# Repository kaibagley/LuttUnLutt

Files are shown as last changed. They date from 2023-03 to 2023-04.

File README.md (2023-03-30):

### 

3x5+2 key split orthogonal BLE keyboard

This fork is a custom version of weteor's Lütt un Lütt, altered such that it is powered by a pair of LiPO batteries rather than coin cells, and uses MX switches.

## Features

- Diode-less pcb, since there are enough GPIO pins on the nice!nano
- full BLE, powered by 3.7v 110mAh LiPO batteries
- MX hotswap sockets
- case files are supplied (stl, dxf, as well as the freecad files)
- supports both nice!nano and pro micro
- QMK, ZMK, etc. support with pro micro, or ZMK with nice!nano

## Prototype

- First prototype printed on 18th March 2023

## what's left to do?

- fix small hole placement error in case
- implement support of Elite-C/Pi
- add mounting holes

## Credit

This repo is inspired by weteor's Lütt un Lütt, please visit this link: https://github.com/weteor/LuttUnLutt to view the original, and support the creator.

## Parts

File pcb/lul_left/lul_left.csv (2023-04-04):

Source: | G:\Keyboards\Thunder-Lightning\pcb\lul_left\lul_left.kicad_sch
Date: | 18/03/2023 10:16:14 PM
Tool: | Eeschema (7.0.0)
Generator: | C:\Program Files\KiCad\7.0\bin\scripting\plugins/bom_csv_grouped_by_value_with_fp.py
Component Count: | 42
Ref | Qnty | Value | Cmp name | Footprint | Description | Vendor | DNP
J1, J2 | 2 | JST Connector | Conn_01x02_Socket | Connector_JST:JST_PH_S2B-PH-K_1x02_P2.00mm_Horizontal | Generic connector, single row, 01x02, script generated
SW1, SW2, SW3, SW4, SW5, SW6, SW7, SW8, SW9, SW10, SW11, SW12, SW14, SW15, SW16, SW17, SW18, SW19, SW20, SW22, SW23, SW24, SW25, SW26, SW27, SW28, SW29, SW30, SW31, SW32, SW33, SW34 | 32 | SW_Push | SW_Push | MX_Only:MXOnly-1U-Hotswap | Push button switch, generic, two pins
SW13, SW21 | 2 | SW_Push | SW_Push | MX_Only:MXOnly-1.75U-Hotswap | Push button switch, generic, two pins
SW_RESET2 | 1 | SW_RESET | SW_Push | random-keyboard-parts:SKQG-1155865 | Push button switch, generic, two pins
SW_RESET_1 | 1 | SW_RESET | SW_Push | random-keyboard-parts:SKQG-1155865 | Push button switch, generic, two pins
SW_SPDT_1, SW_SPDT_2 | 2 | SW_SPDT | SW_SPDT | Button_Switch_SMD:SW_SPDT_PCM12 | Switch, single pole double throw
U1, U2 | 2 | nice_nano | nice_nano | nice-nano-kicad:nice_nano

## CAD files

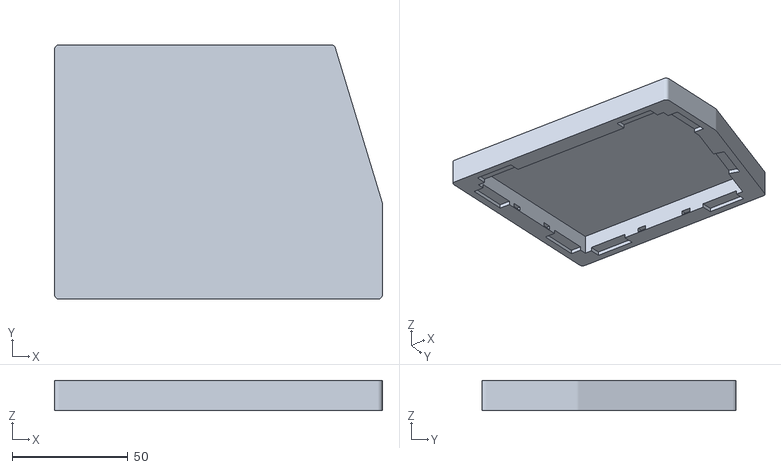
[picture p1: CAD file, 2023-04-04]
case_plate/RightBottom.stl
141.8 x 110.0 x 13.0

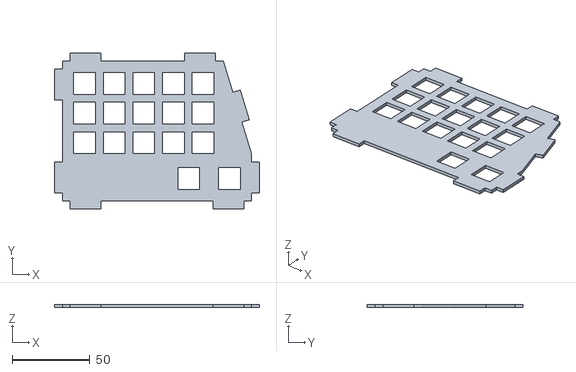
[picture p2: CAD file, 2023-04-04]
case_plate/Plate.stl
131.8 x 100.0 x 2.00

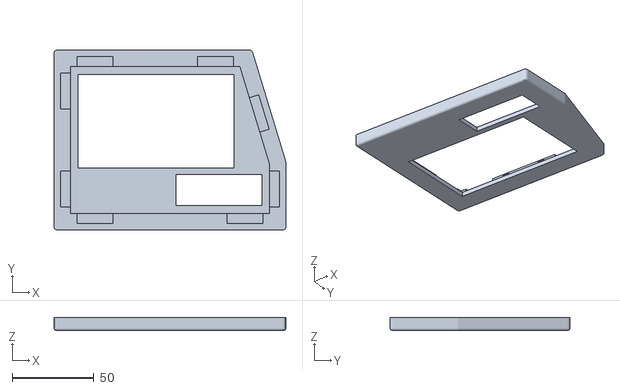
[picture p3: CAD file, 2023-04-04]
case_plate/RightTop.stl
141.8 x 110.0 x 8.00

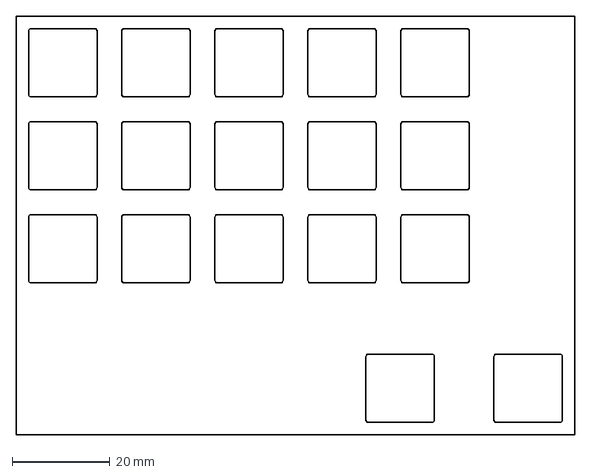
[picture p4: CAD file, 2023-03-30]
case_plate/plate-2023-03-20T13 58 18.676Z.dxf
114.3 x 85.7 mm

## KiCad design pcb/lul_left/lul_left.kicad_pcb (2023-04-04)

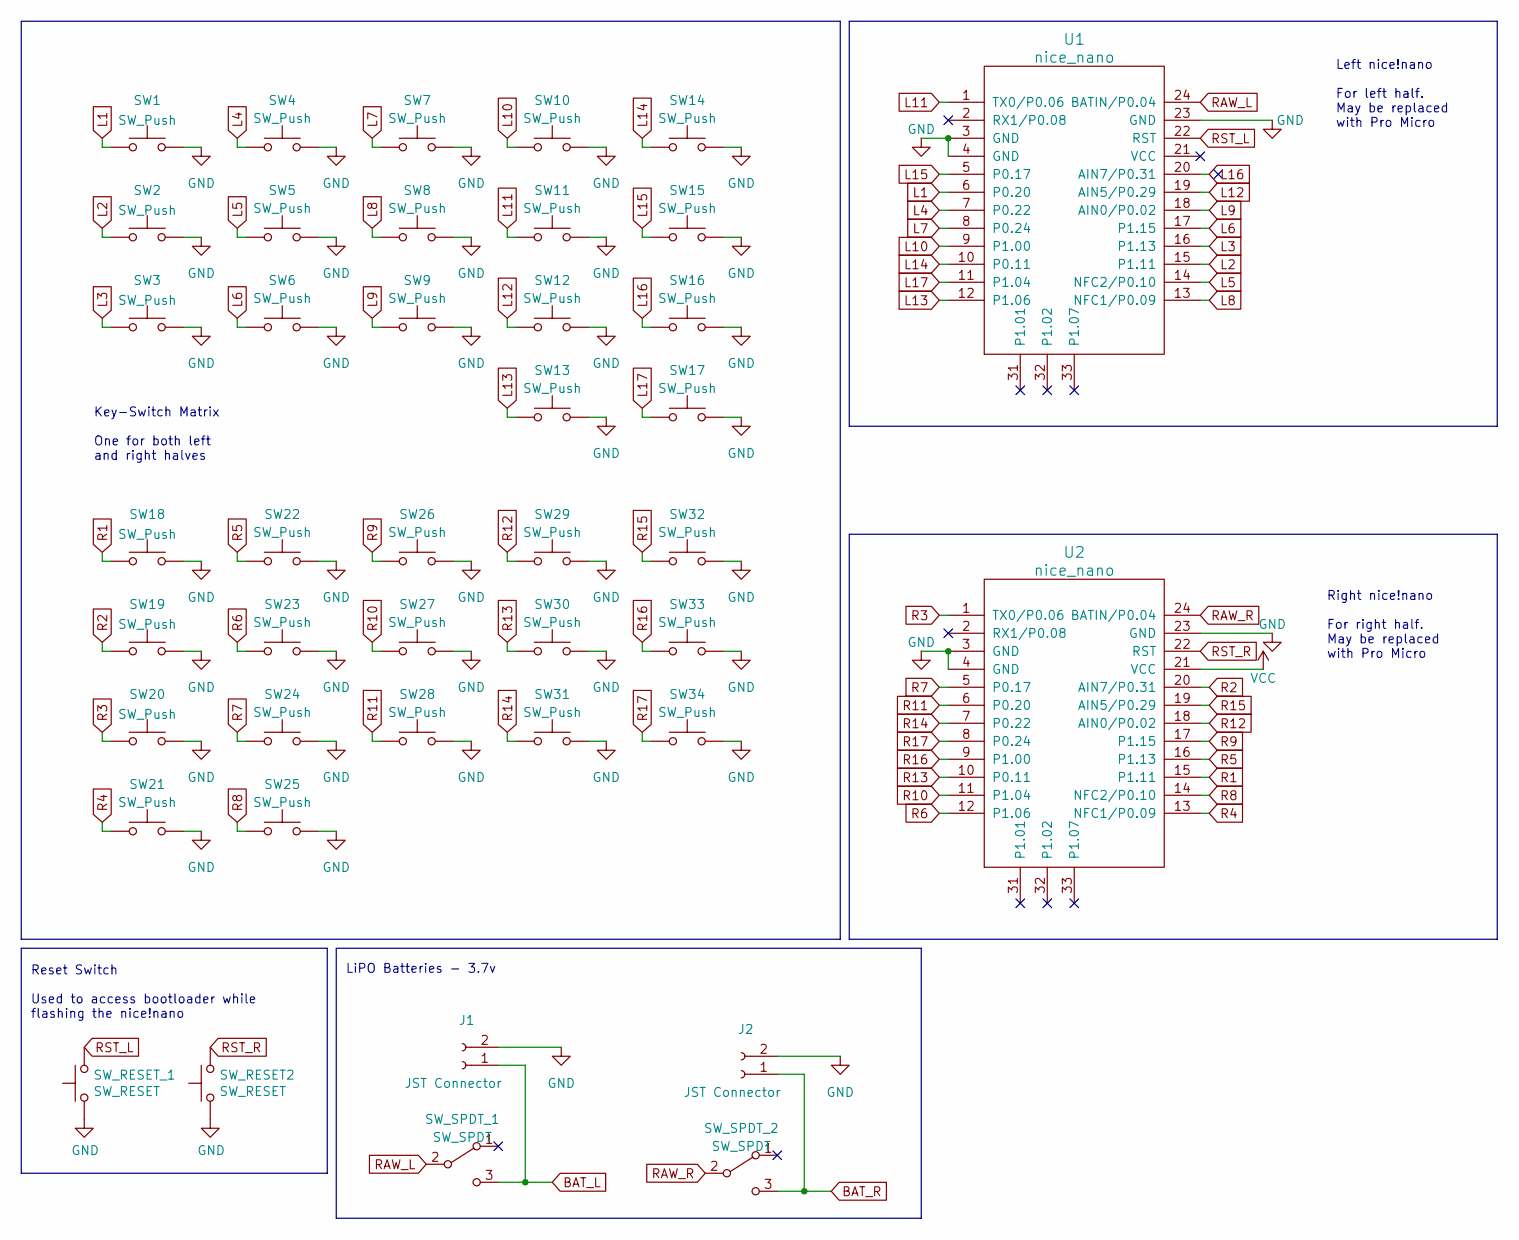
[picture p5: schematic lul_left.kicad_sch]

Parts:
J1, J2: JST Connector; JST_PH_S2B-PH-K_1x02_P2.00mm_Horizontal
SW1, SW2, SW3, SW4, SW5, SW6, SW7, SW8, SW9, SW10, SW11, SW12, SW14, SW15, SW16, SW17, SW18, SW19, SW20, SW22, SW23, SW24, SW25, SW26, SW27, SW28, SW29, SW30, SW31, SW32, SW33, SW34: SW_Push; MXOnly-1U-Hotswap
SW13, SW21: SW_Push; MXOnly-1.75U-Hotswap
SW_RESET2: SW_RESET; SKQG-1155865
SW_RESET_1: SW_RESET; SKQG-1155865
SW_SPDT_1, SW_SPDT_2: SW_SPDT; SW_SPDT_PCM12
U1, U2: nice_nano

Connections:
BAT_L: J1.1, SW_SPDT_1.3 (C)
BAT_R: J2.1, SW_SPDT_2.3 (C)
GND: J1.2, J2.2, SW1.2, SW2.2, SW3.2, SW4.2, SW5.2, SW6.2, SW7.2, SW8.2, SW9.2, SW10.2, SW11.2, SW12.2, SW13.2, SW14.2, SW15.2, SW16.2, SW17.2, SW18.2, SW19.2, SW20.2, SW21.2, SW22.2, SW23.2, SW24.2, SW25.2, SW26.2, SW27.2, SW28.2, SW29.2, SW30.2, SW31.2, SW32.2, SW33.2, SW34.2, SW_RESET2.1, SW_RESET_1.1, U1.3 (GND), U1.4 (GND), U1.23 (GND), U2.3 (GND), U2.4 (GND), U2.23 (GND)
L1: SW1.1, U1.6 (P0.20)
L2: SW2.1, U1.15 (P1.11)
L3: SW3.1, U1.16 (P1.13)
L4: SW4.1, U1.7 (P0.22)
L5: SW5.1, U1.14 (NFC2/P0.10)
L6: SW6.1, U1.17 (P1.15)
L7: SW7.1, U1.8 (P0.24)
L8: SW8.1, U1.13 (NFC1/P0.09)
L9: SW9.1, U1.18 (AIN0/P0.02)
L10: SW10.1, U1.9 (P1.00)
L11: SW11.1, U1.1 (TX0/P0.06)
L12: SW12.1, U1.19 (AIN5/P0.29)
L13: SW13.1, U1.12 (P1.06)
L14: SW14.1, U1.10 (P0.11)
L15: SW15.1, U1.5 (P0.17)
L16: SW16.1, U1.20 (AIN7/P0.31)
L17: SW17.1, U1.11 (P1.04)
R1: SW18.1, U2.15 (P1.11)
R2: SW19.1, U2.20 (AIN7/P0.31)
R3: SW20.1, U2.1 (TX0/P0.06)
R4: SW21.1, U2.13 (NFC1/P0.09)
R5: SW22.1, U2.16 (P1.13)
R6: SW23.1, U2.12 (P1.06)
R7: SW24.1, U2.5 (P0.17)
R8: SW25.1, U2.14 (NFC2/P0.10)
R9: SW26.1, U2.17 (P1.15)
R10: SW27.1, U2.11 (P1.04)
R11: SW28.1, U2.6 (P0.20)
R12: SW29.1, U2.18 (AIN0/P0.02)
R13: SW30.1, U2.10 (P0.11)
R14: SW31.1, U2.7 (P0.22)
R15: SW32.1, U2.19 (AIN5/P0.29)
R16: SW33.1, U2.9 (P1.00)
R17: SW34.1, U2.8 (P0.24)
RAW_L: SW_SPDT_1.2 (B), U1.24 (BATIN/P0.04)
RAW_R: SW_SPDT_2.2 (B), U2.24 (BATIN/P0.04)
RST_L: SW_RESET_1.2, U1.22 (RST)
RST_R: SW_RESET2.2, U2.22 (RST)
VCC: U2.21 (VCC)

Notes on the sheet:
Key-Switch Matrix One for both left and right halves
LiPO Batteries - 3.7v
Right nice!nano For right half. May be replaced with Pro Micro
Reset Switch Used to access bootloader while flashing the nice!nano
Left nice!nano For left half. May be replaced with Pro Micro

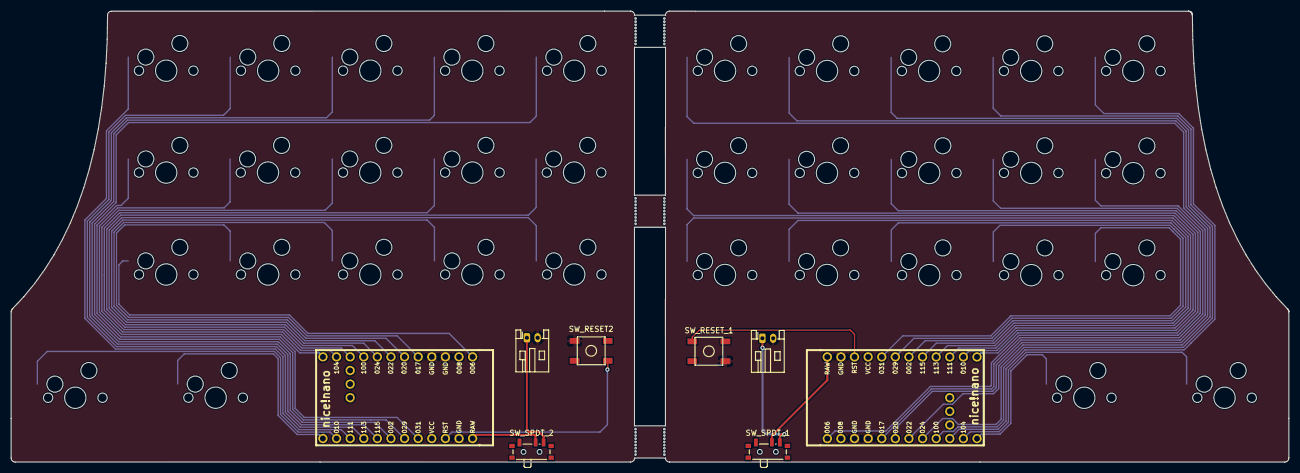
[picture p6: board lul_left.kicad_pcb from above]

Board: 2 copper layers, 238.5 x 84.2 mm, 44 parts (0 on the bottom side), 41 nets.

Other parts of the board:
G1, G2: LOGO

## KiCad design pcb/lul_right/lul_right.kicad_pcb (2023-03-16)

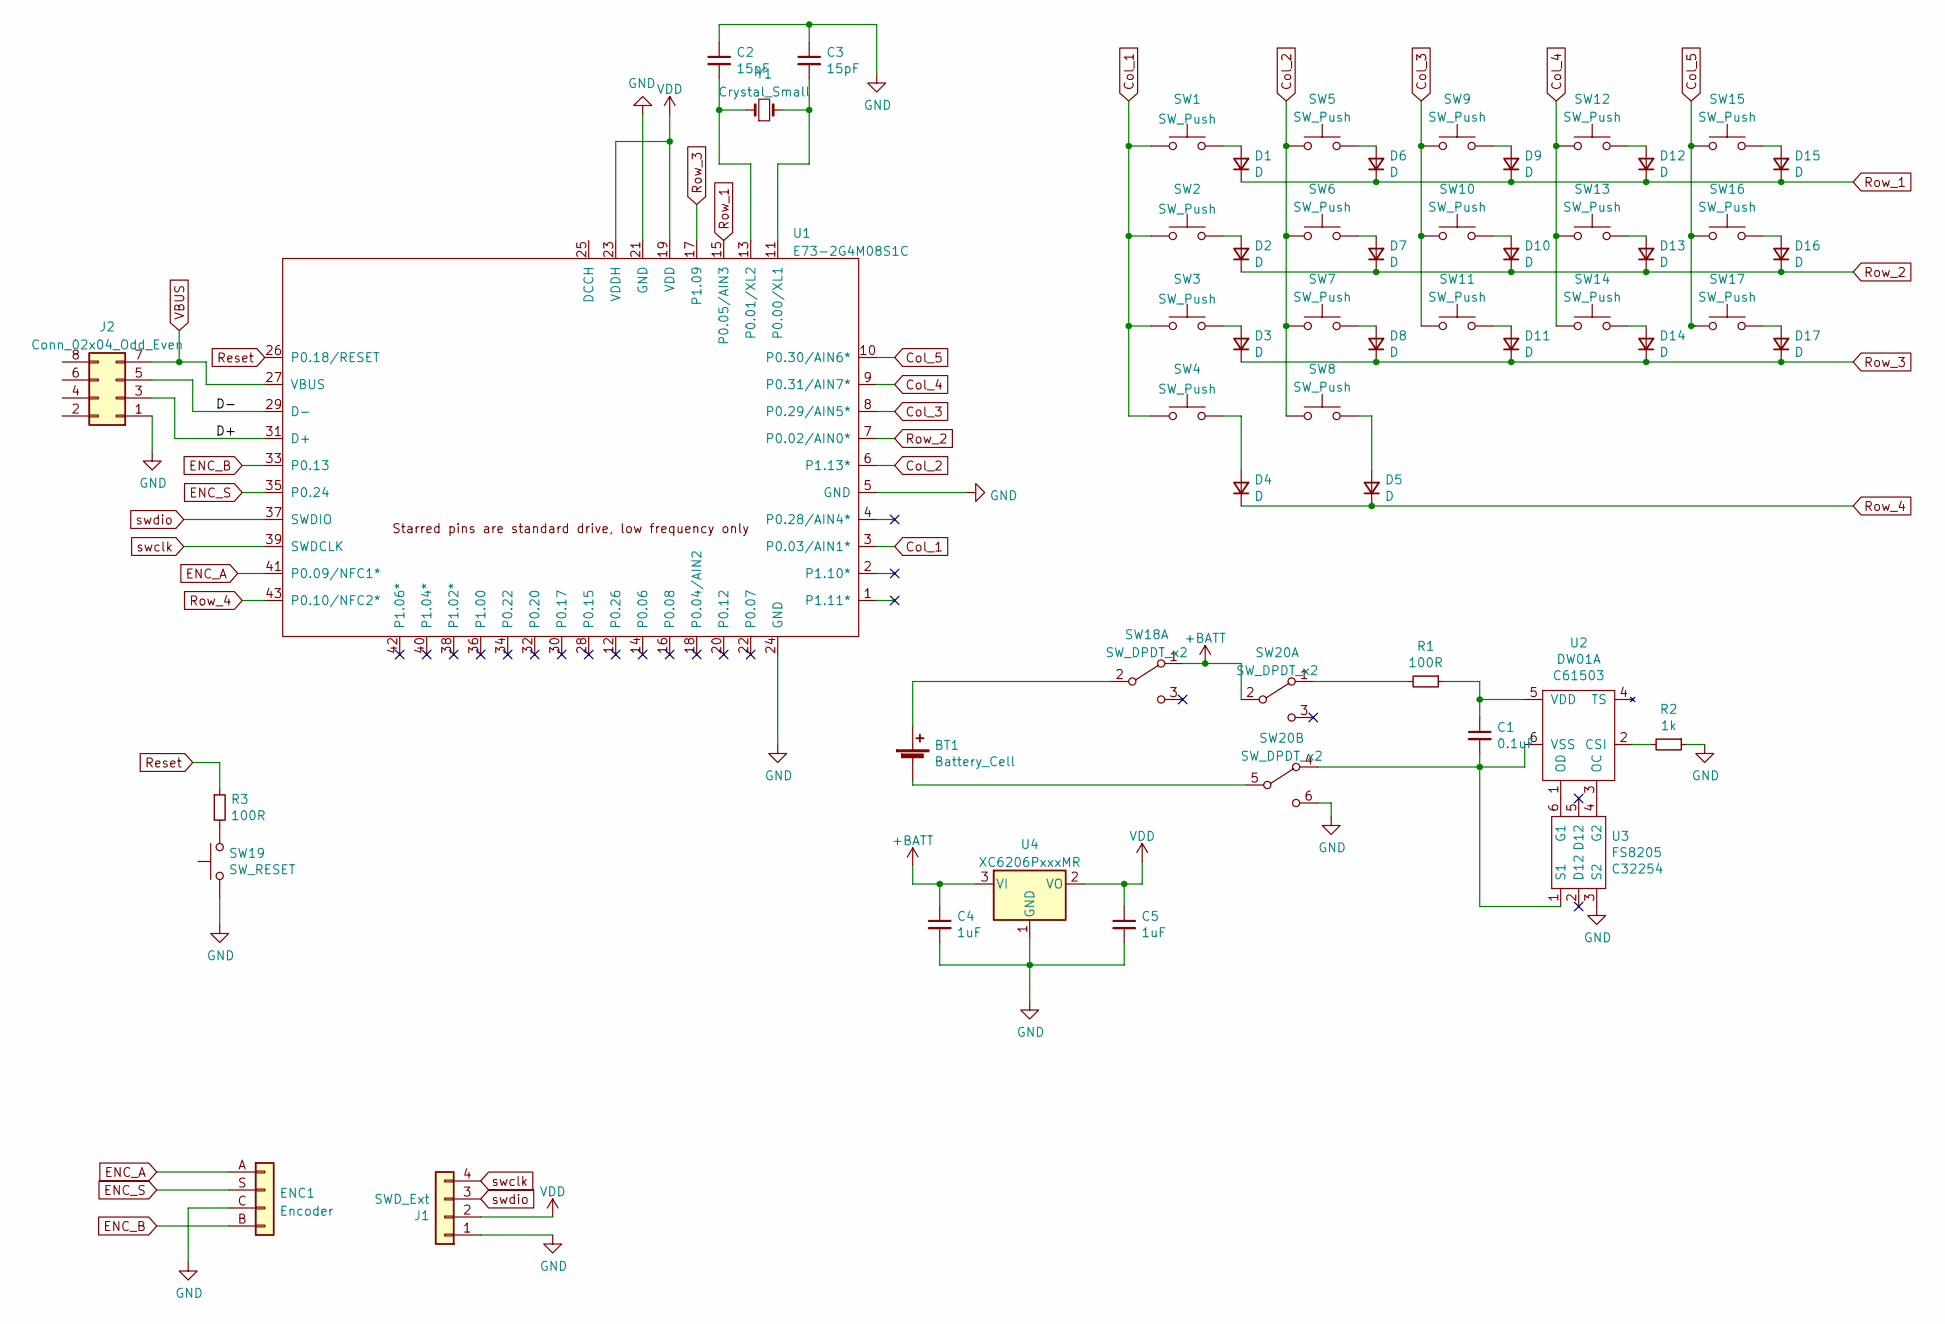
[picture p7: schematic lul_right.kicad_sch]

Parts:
BT1: Battery_Cell; Coin Cell 2032
C1: 0.1uF; C_0603_1608Metric
C2, C3: 15pF; C_0603_1608Metric
C4, C5: 1uF; C_0603_1608Metric
D1, D2, D3, D4, D5, D6, D7, D8, D9, D10, D11, D12, D13, D14, D15, D16, D17: D; D_SOD-123
ENC1: Encoder; Mitsumi_SIQ-02FVS3
J1: SWD_Ext; PinHeader_1x04_P2.54mm_Vertical
J2: Conn_02x04_Odd_Even; PinSocket_2x04_P1.27mm_Vertical
R1, R3: 100R; R_0603_1608Metric
R2: 1k; R_0603_1608Metric
SW1, SW2, SW3, SW4, SW5, SW6, SW7, SW9, SW10, SW11, SW12, SW13, SW14, SW15, SW16, SW17: SW_Push; ChocV1_V2_Hotswap_3d
SW8: SW_Push; ChocV1_V2_Hotswap_1.5u
SW18, SW20: SW_DPDT_x2; DPDT - C2837066
SW19: SW_RESET; Micro_Push_Button_3x6x2.5mm
U1: E73-2G4M08S1C; E73-2G4M08S1C_bottom
U2: DW01A; SOT-23-6; LCSC C61503
U3: FS8205; SOT-23-6; LCSC C32254
U4: XC6206PxxxMR; SOT-23
Y1: Crystal_Small; Crystal_SMD_3215-2Pin_3.2x1.5mm

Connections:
+BATT: C4.1, SW18.1 (A), SW20.2 (B), U4.3 (VI)
/D+: J2.3, U1.31 (D+)
/D-: J2.5, U1.29 (D-)
Col_1: SW1.1, SW2.1, SW3.1, SW4.1, U1.3 (P0.03/AIN1*)
Col_2: SW5.1, SW6.1, SW7.1, SW8.1, U1.6 (P1.13*)
Col_3: SW9.1, SW10.1, SW11.1, U1.8 (P0.29/AIN5*)
Col_4: SW12.1, SW13.1, SW14.1, U1.9 (P0.31/AIN7*)
Col_5: SW15.1, SW16.1, SW17.1, U1.10 (P0.30/AIN6*)
ENC_A: ENC1.A, U1.41 (P0.09/NFC1*)
ENC_B: ENC1.B, U1.33 (P0.13)
ENC_S: ENC1.S, U1.35 (P0.24)
GND: C2.1, C3.1, C4.2, C5.2, ENC1.C, J1.1, J2.1, R2.1, SW19.1, SW20.6 (C), U1.5 (GND), U1.21 (GND), U1.24 (GND), U3.3 (S2), U4.1 (GND)
unnamed: BT1.1 (+), SW18.2 (B)
unnamed: BT1.2 (-), SW20.5 (B)
unnamed: C1.1, R1.1, U2.5 (VDD)
unnamed: C1.2, SW20.4 (A), U2.6 (VSS), U3.1 (S1)
unnamed: C2.2, U1.13 (P0.01/XL2), Y1.1
unnamed: C3.2, U1.11 (P0.00/XL1), Y1.2
unnamed: D1.2 (A), SW1.2
unnamed: D2.2 (A), SW2.2
unnamed: D3.2 (A), SW3.2
unnamed: D4.2 (A), SW4.2
unnamed: D5.2 (A), SW8.2
unnamed: D6.2 (A), SW5.2
unnamed: D7.2 (A), SW6.2
unnamed: D8.2 (A), SW7.2
unnamed: D9.2 (A), SW9.2
unnamed: D10.2 (A), SW10.2
unnamed: D11.2 (A), SW11.2
unnamed: D12.2 (A), SW12.2
unnamed: D13.2 (A), SW13.2
unnamed: D14.2 (A), SW14.2
unnamed: D15.2 (A), SW15.2
unnamed: D16.2 (A), SW16.2
unnamed: D17.2 (A), SW17.2
unnamed: R1.2, SW20.1 (A)
unnamed: R2.2, U2.2 (CSI)
unnamed: R3.2, SW19.2
unnamed: U2.1 (OD), U3.6 (G1)
unnamed: U2.3 (OC), U3.4 (G2)
Reset: R3.1, U1.26 (P0.18/RESET)
Row_1: D1.1 (K), D6.1 (K), D9.1 (K), D12.1 (K), D15.1 (K), U1.15 (P0.05/AIN3)
Row_2: D2.1 (K), D7.1 (K), D10.1 (K), D13.1 (K), D16.1 (K), U1.7 (P0.02/AIN0*)
Row_3: D3.1 (K), D8.1 (K), D11.1 (K), D14.1 (K), D17.1 (K), U1.17 (P1.09)
Row_4: D4.1 (K), D5.1 (K), U1.43 (P0.10/NFC2*)
VBUS: J2.7, U1.27 (VBUS)
VDD: C5.1, J1.2, U1.19 (VDD), U1.23 (VDDH), U4.2 (VO)
swclk: J1.4, U1.39 (SWDCLK)
swdio: J1.3, U1.37 (SWDIO)

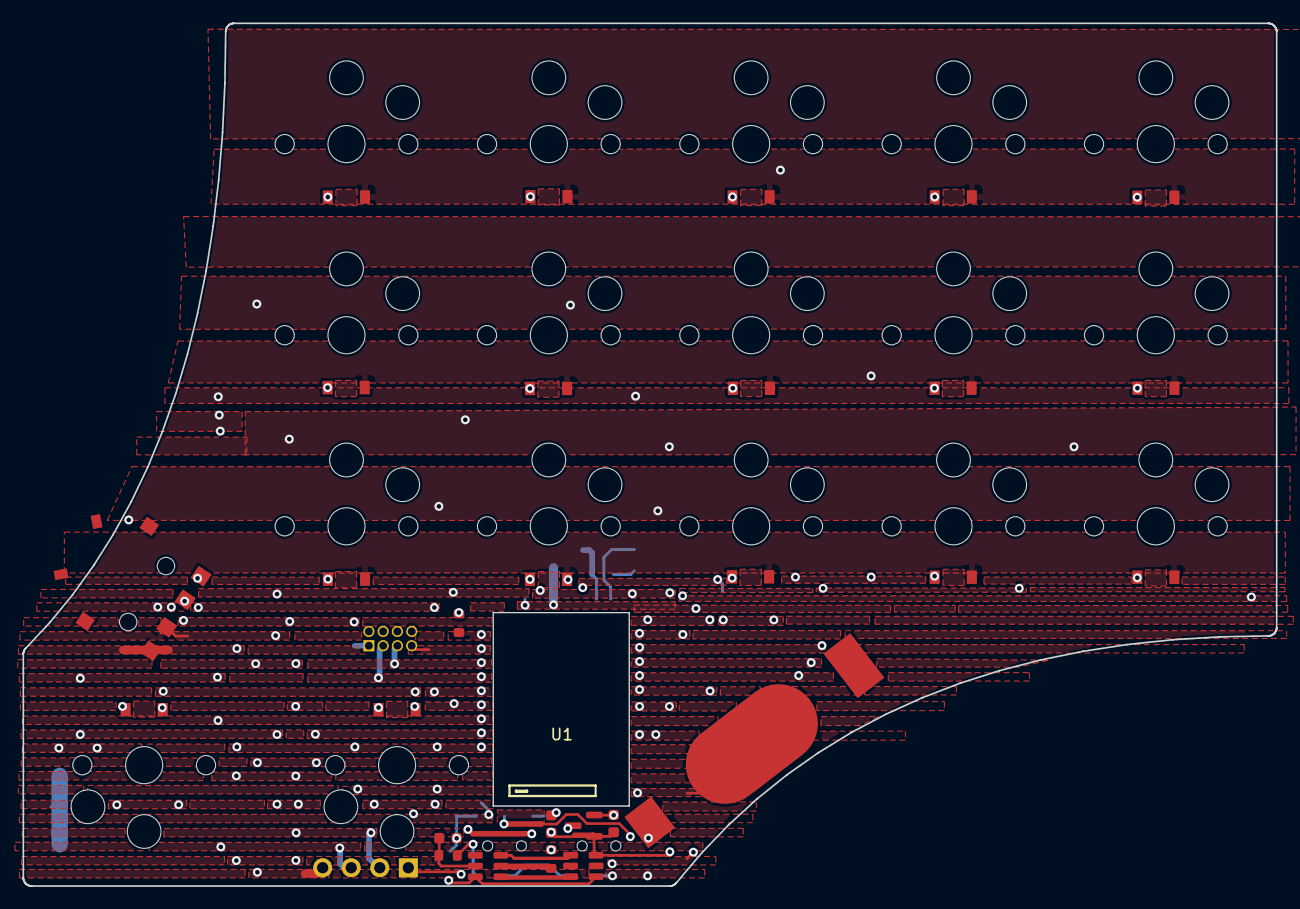
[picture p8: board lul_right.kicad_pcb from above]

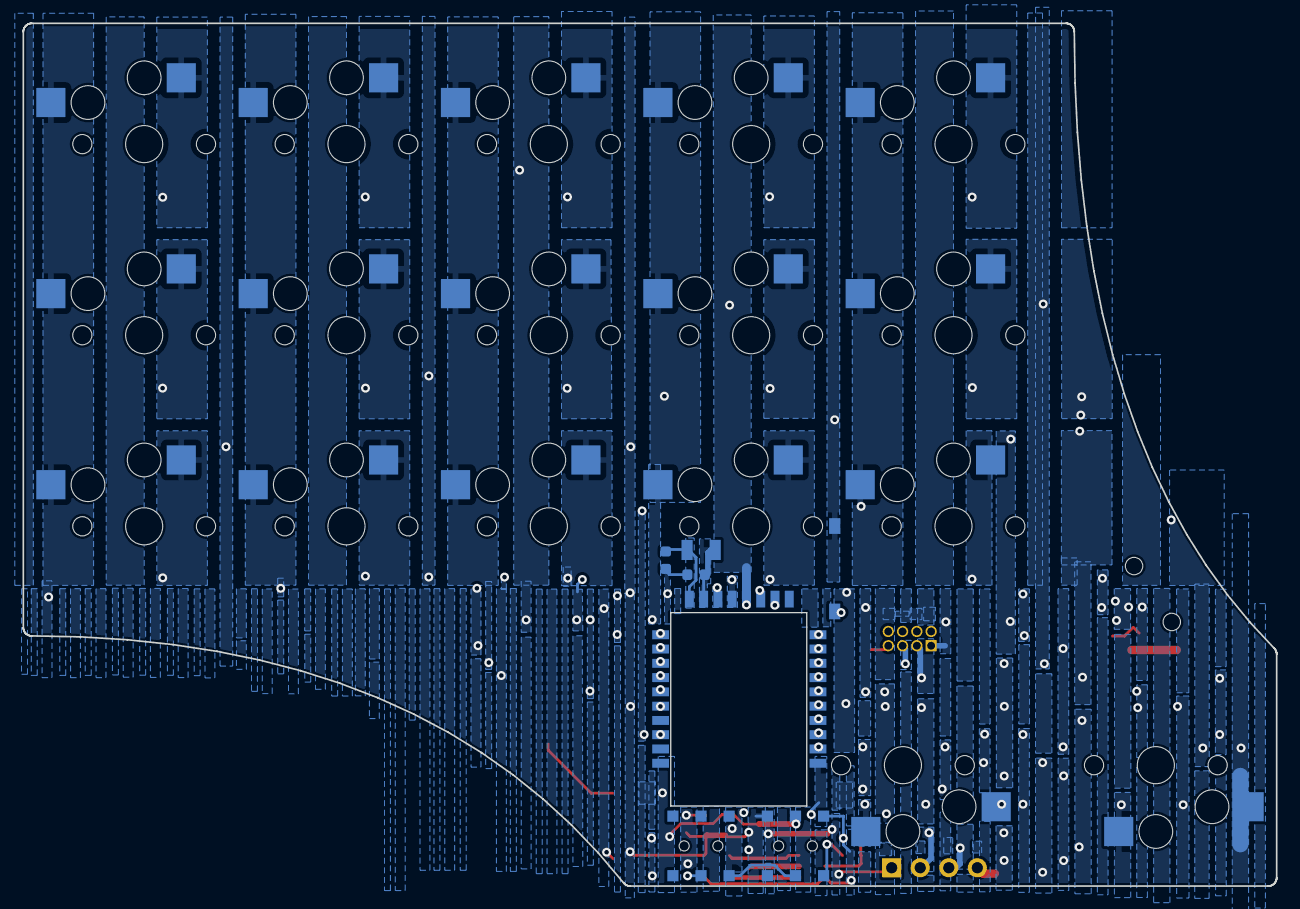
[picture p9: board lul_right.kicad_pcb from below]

Board: 2 copper layers, 111.5 x 76.8 mm, 54 parts (7 on the bottom side), 49 nets.

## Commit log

2023-03-15 added libraries and a few edits to schematic
    [lul_left.kicad_sch]
2023-03-15 remove submodules
    [lul_left.kicad_pcb, lul_left.kicad_sch, lul_right.kicad_pcb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]
2023-03-15 Add nice!nano, add on/off switch
    [lul_left.kicad_sch]
2023-03-16 Fixed switch count
    [lul_left.kicad_sch]
2023-03-16 add controllers for both keyswitch matrices
    [lul_left.kicad_pcb, lul_left.kicad_sch, lul_right.kicad_pcb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]
2023-03-17 switches positioned properly
    [lul_left.kicad_pcb, lul_left.kicad_sch]
2023-03-17 change schematic to be diode-less
    [lul_left.kicad_sch]
2023-03-17 move components to temporary locations
    [lul_left.kicad_pcb, lul_left.kicad_sch]
2023-03-18 move components, add dimension labels, add breakable tabs between pcb bodies
    [lul_left.kicad_pcb, lul_left.kicad_sch]
2023-03-18 touch up dimensions and positions
    [lul_left.kicad_pcb]
2023-03-18 route switches nicely
    [lul_left.kicad_pcb, lul_left.kicad_sch]
2023-03-18 route fully. Just need ground fill
    [lul_left.kicad_pcb, lul_left.kicad_sch]
2023-03-18 remove the old fill zones
    [lul_left.kicad_pcb]
2023-03-18 add full grounded copper fills to top and bottom layers
    [lul_left.kicad_pcb]
2023-03-18 add randomly placed vias to remove any potential capacitance between the copper fills? probably not necessary but i feel like im using my physics degree by doing this
    [lul_left.kicad_pcb]
2023-03-18 fix small connection issue
    [lul_left.kicad_pcb, lul_left.kicad_sch]
2023-03-18 edge cuts fixed
    [lul_left.kicad_pcb]
2023-03-18 fix footprint courtyard error in MX_1U and MX_1.75U
    [lul_left.kicad_pcb]
2023-03-30 Add case and plate
    [Plate.stl, Right bottom.stl, RightTop.stl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]
2023-04-04 updated case
    [Plate.stl, Right bottom.stl, RightBottom.stl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]
2023-04-04 updated case bottom
    [RightBottom.stl]
